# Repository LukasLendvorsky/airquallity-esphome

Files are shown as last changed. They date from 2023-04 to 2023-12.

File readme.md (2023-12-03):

# AirquaLLity-esphome

Air-quality sensor (CO2, particulate matter, ...) in a nice 3D printed package with LED bar visualization. Using ESPHome, compatible with HomeAssitant.

## Images

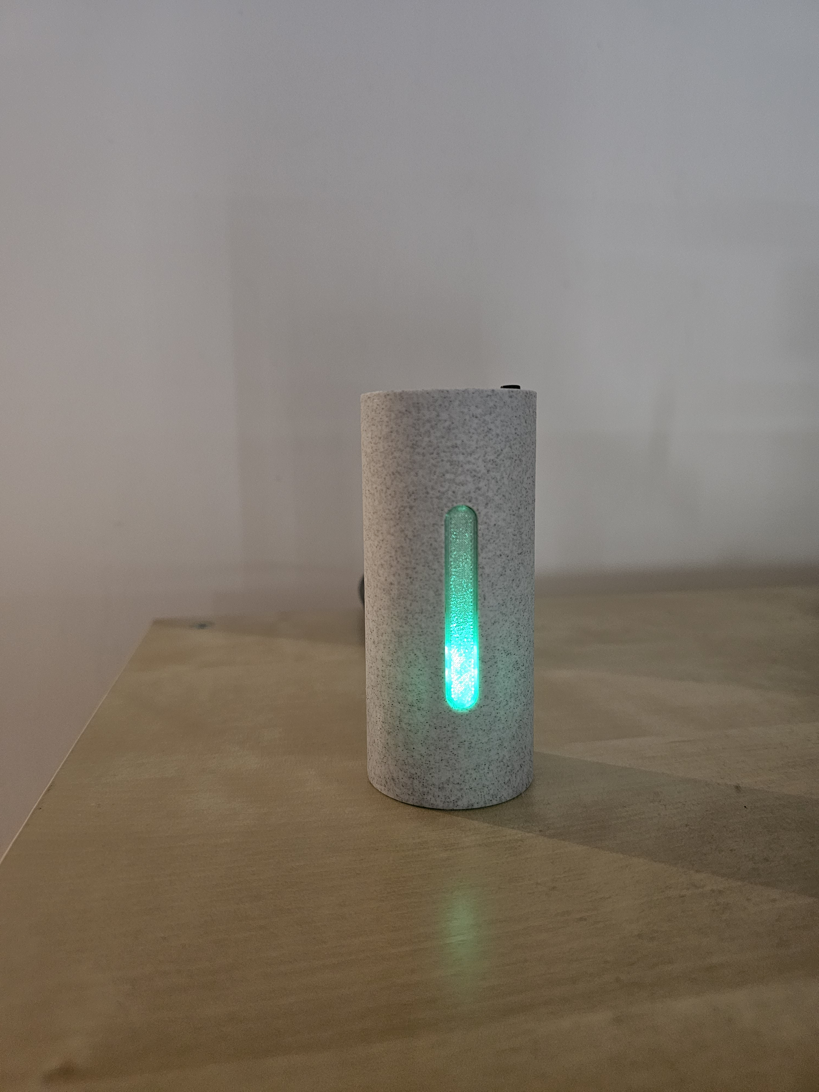
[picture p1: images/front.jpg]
front view

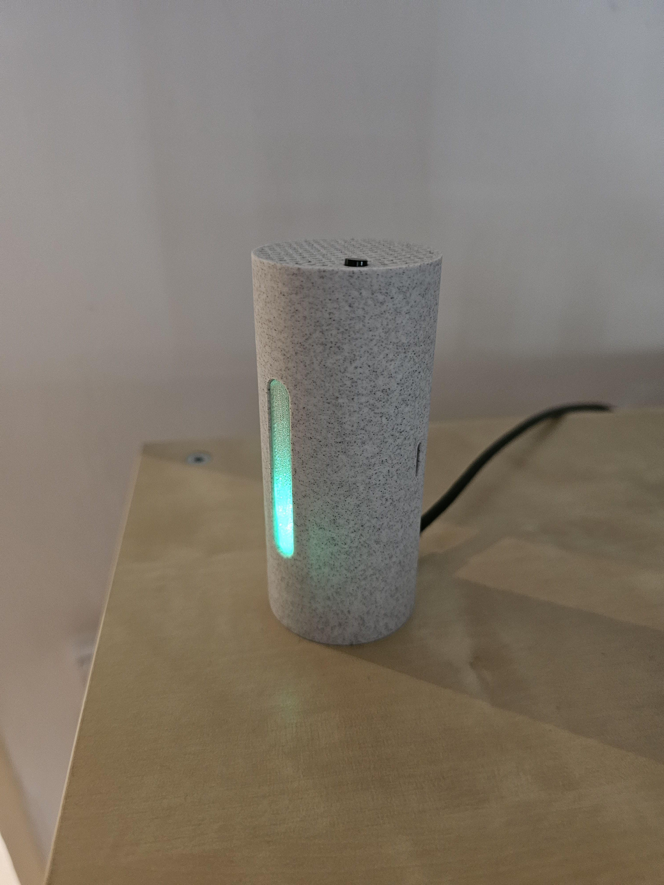
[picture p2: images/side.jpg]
side view


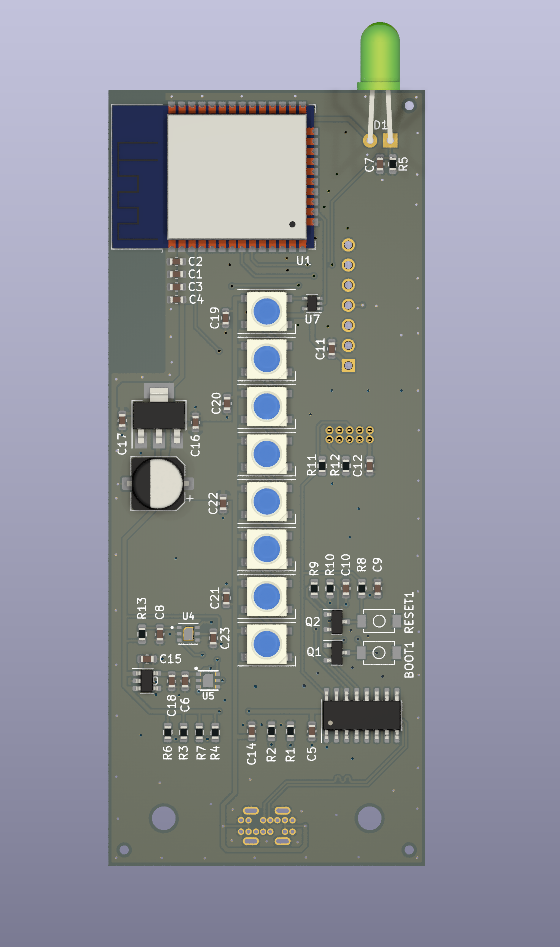
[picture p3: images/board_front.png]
board front view

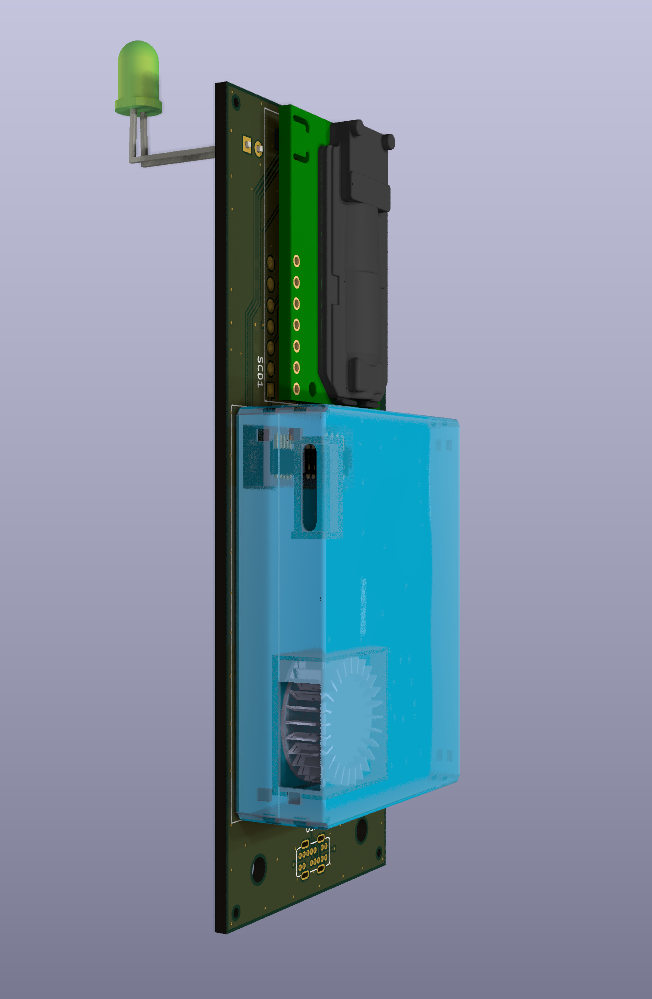
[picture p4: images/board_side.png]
side view


## Features
- Wi-Fi
- RGB LED bar for quick visual air-quality indication
- HomeAssistant compatible

### Sensors:
 - Accurate CO2 using dual NDIR sensor (SCD30) 
 - Particulate matter (<10µm, <2.5µm, <1µm)
 - Temperature
 - Humidity
 - Illumination (amount of light)
 - VOC (Volatile organic compound) sensor
 - NOx sensor

## How to build

Manufactury files available, see schematic/jlcpcb. They can assemble most of the bord, however you'll need to solder at least CO2 sensor & particulate matter sensor yourself.

## Firmware 
 See https://esphome.io/guides/getting_started_command_line.html

- set your Wi-Fi credentials in firmware\secrets.yaml
- go to firmware directory
- Run: ```esphome run llairquality.yaml```

## License

See [LICENSE](LICENSE)

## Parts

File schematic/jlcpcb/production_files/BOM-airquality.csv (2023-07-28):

Comment | Designator | Footprint | LCSC
ALS-PDIC243-3B | D1 | ALS-PDIC243-3B | C141718
100nF | C10,C2,C3,C4,C5,C6,C7 | C_0603_1608Metric | C14663
5K1 | R1,R2 | R_0603_1608Metric | C14677
SCD30 (CO2) | SCD1 | MODULE_SCD30 | C1519271
1uF | C15,C18,C23,C8 | C_0603_1608Metric | C15849
BC817 | Q1,Q2 | SOT-23 | C2137
4.7 | R13 | R_0603_1608Metric | C23164
10K | R10,R11,R12,R3,R4,R5,R6,R7,R8,R9 | R_0603_1608Metric | C25804
WS2812B | D2,D3,D4,D5,D6,D7,D8,D9 | LED_WS2812B_PLCC4_5.0x5.0mm_P3.2mm | C2761795
USB_C_Receptacle | USB1 | Hanbo Electronic MC-802YC-H100 | C3039300
SGP41-D-R4 | U4 | XDCR_SGP41-D-R4 | C3659325
TLV70218_SOT23-5 | U9 | SOT-23-5 | C44435
SGP30 | U5 | SGP30 | C514454
ESP32-WROOM-32D | U1 | ESP32-WROOM-32D | C529577
22uF | C1,C11,C12,C14,C16,C17,C19,C20,C21,C22,C9 | C_0603_1608Metric | C59461
AMS1117-3.3 | U8 | SOT-223-3_TabPin2 | C6186
C_Polarized | C13 | CP_Elec_6.3x5.4 | C72494
SN74LV1T34DCK | U7 | SOT-353_SC-70-5 | C78541
SW_Push | BOOT1,RESET1 | GT-TC029B-H025-L1N | C843669
CH340C | U2 | SOIC-16_3.9x9.9mm_P1.27mm | C84681
PMS7003T | U3 | PMS7003

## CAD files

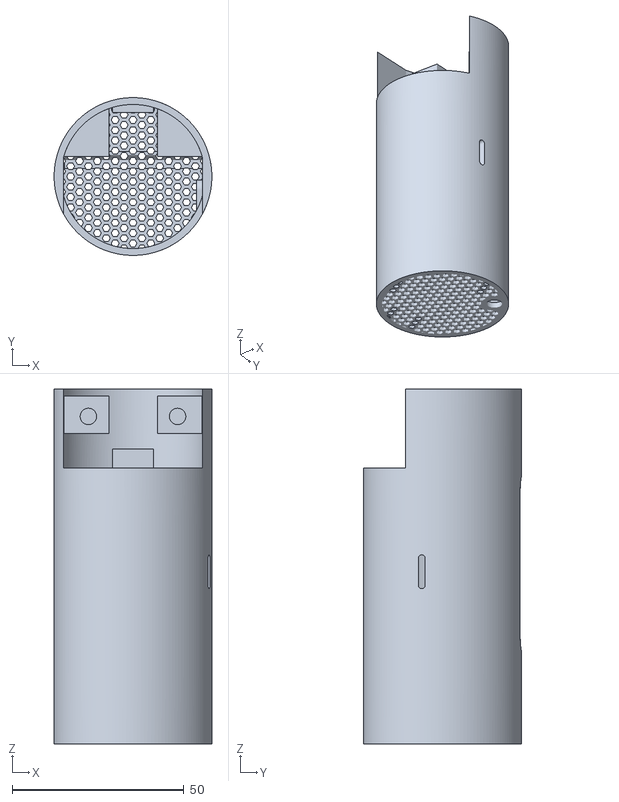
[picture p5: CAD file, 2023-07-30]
case/Case1.stl
46.0 x 46.0 x 103.5

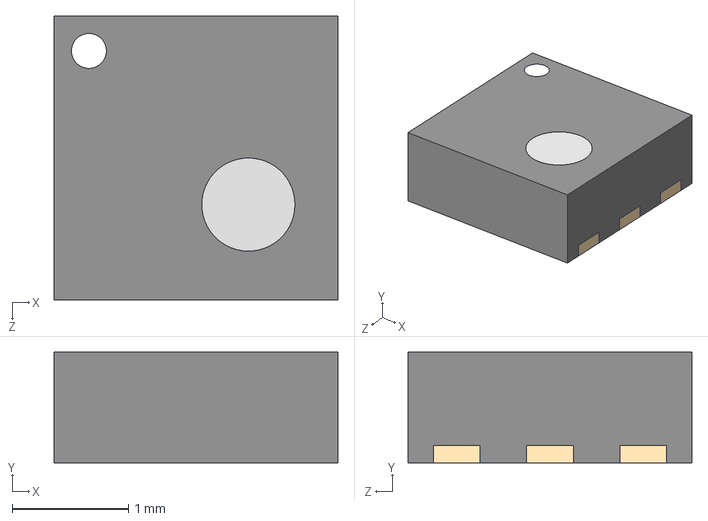
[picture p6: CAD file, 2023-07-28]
schematic/symbols/SGP41-D-R4.step
2.44 x 0.95 x 2.44 mm

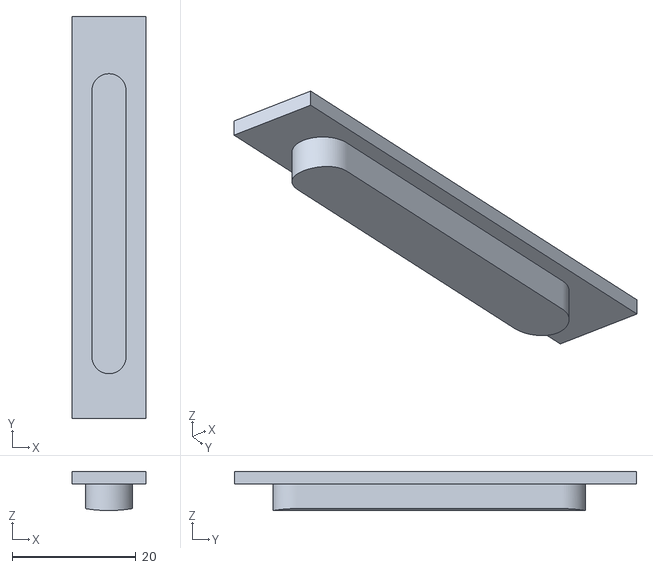
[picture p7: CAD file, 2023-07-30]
case/LighBar.stl
11.9 x 64.9 x 6.32

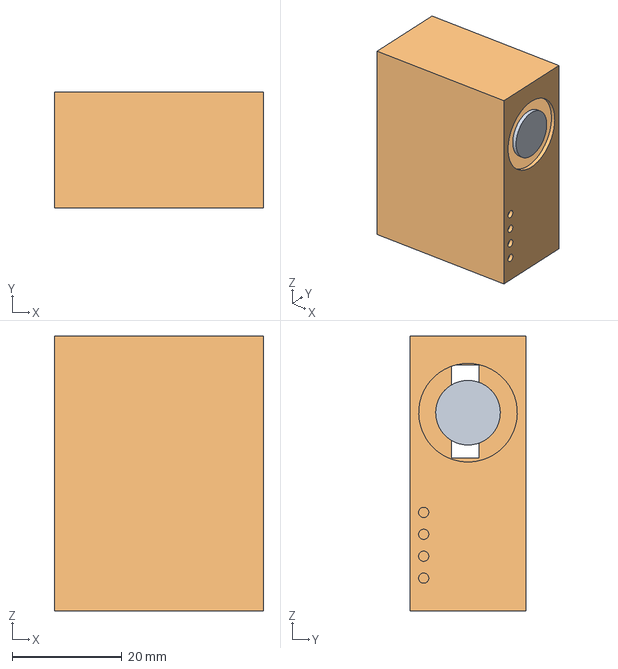
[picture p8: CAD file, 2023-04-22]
schematic/symbols/pms5003.stp
38.2 x 21.2 x 50.2 mm

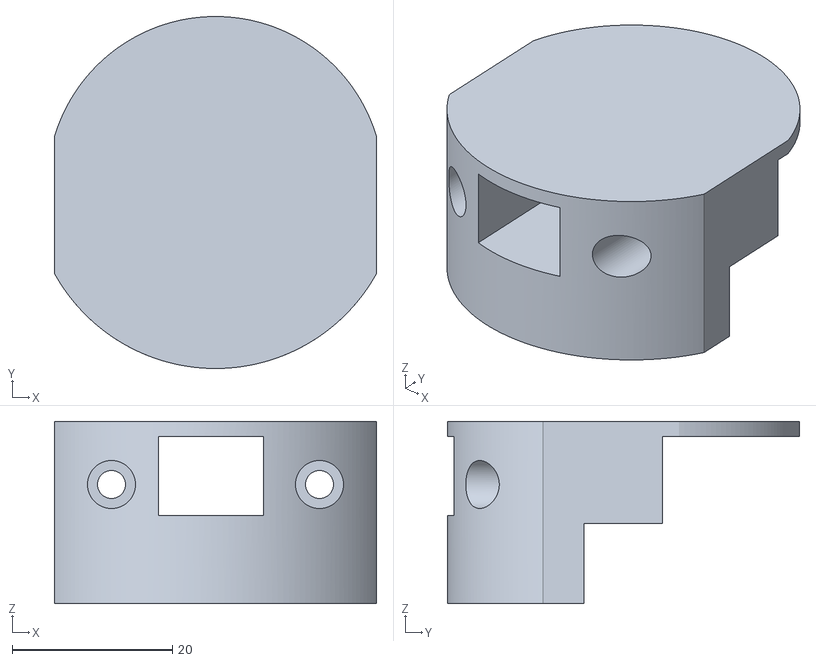
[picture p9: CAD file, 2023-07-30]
case/BottomCap.stl
40.3 x 44.0 x 22.8

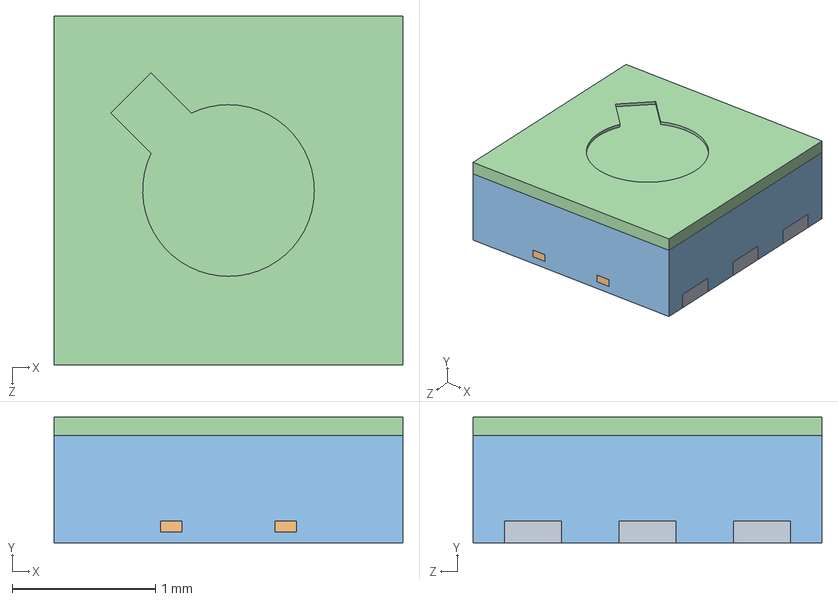
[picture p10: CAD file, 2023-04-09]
schematic/symbols/SGP30-2.5K--3DModel-STEP-1.STEP
2.44 x 0.88 x 2.44 mm

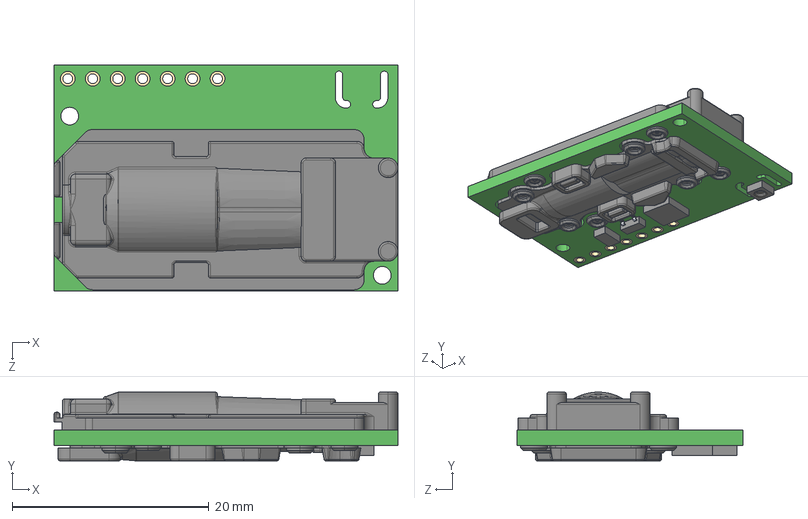
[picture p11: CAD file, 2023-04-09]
schematic/symbols/SCD30.step
35.0 x 7.00 x 23.0 mm

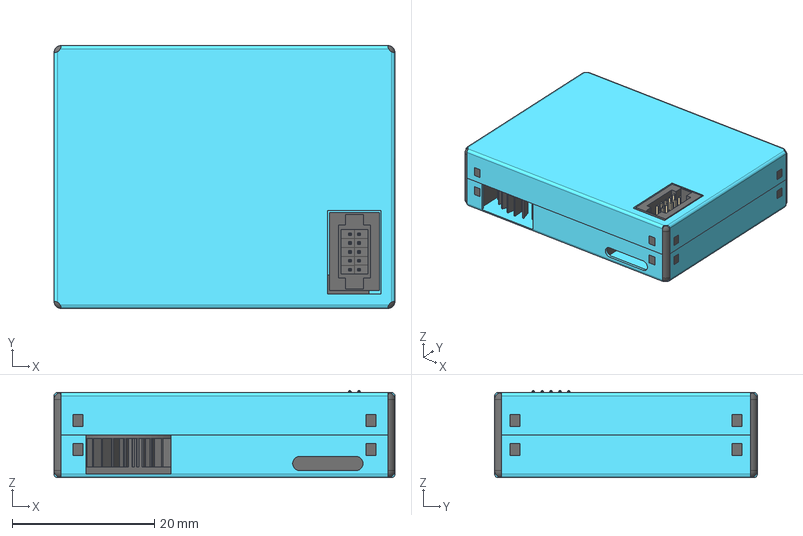
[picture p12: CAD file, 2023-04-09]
schematic/symbols/pms7003.stp
48.0 x 37.0 x 12.3 mm
fan^pms7003
plastic^pms7003
metal_cover_connector
metal_cover_connector_1
1_27mm_pin_right_angle x 10
1_27mm_plastic_for_pin x 10

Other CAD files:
schematic/symbols/pms5003.ipt

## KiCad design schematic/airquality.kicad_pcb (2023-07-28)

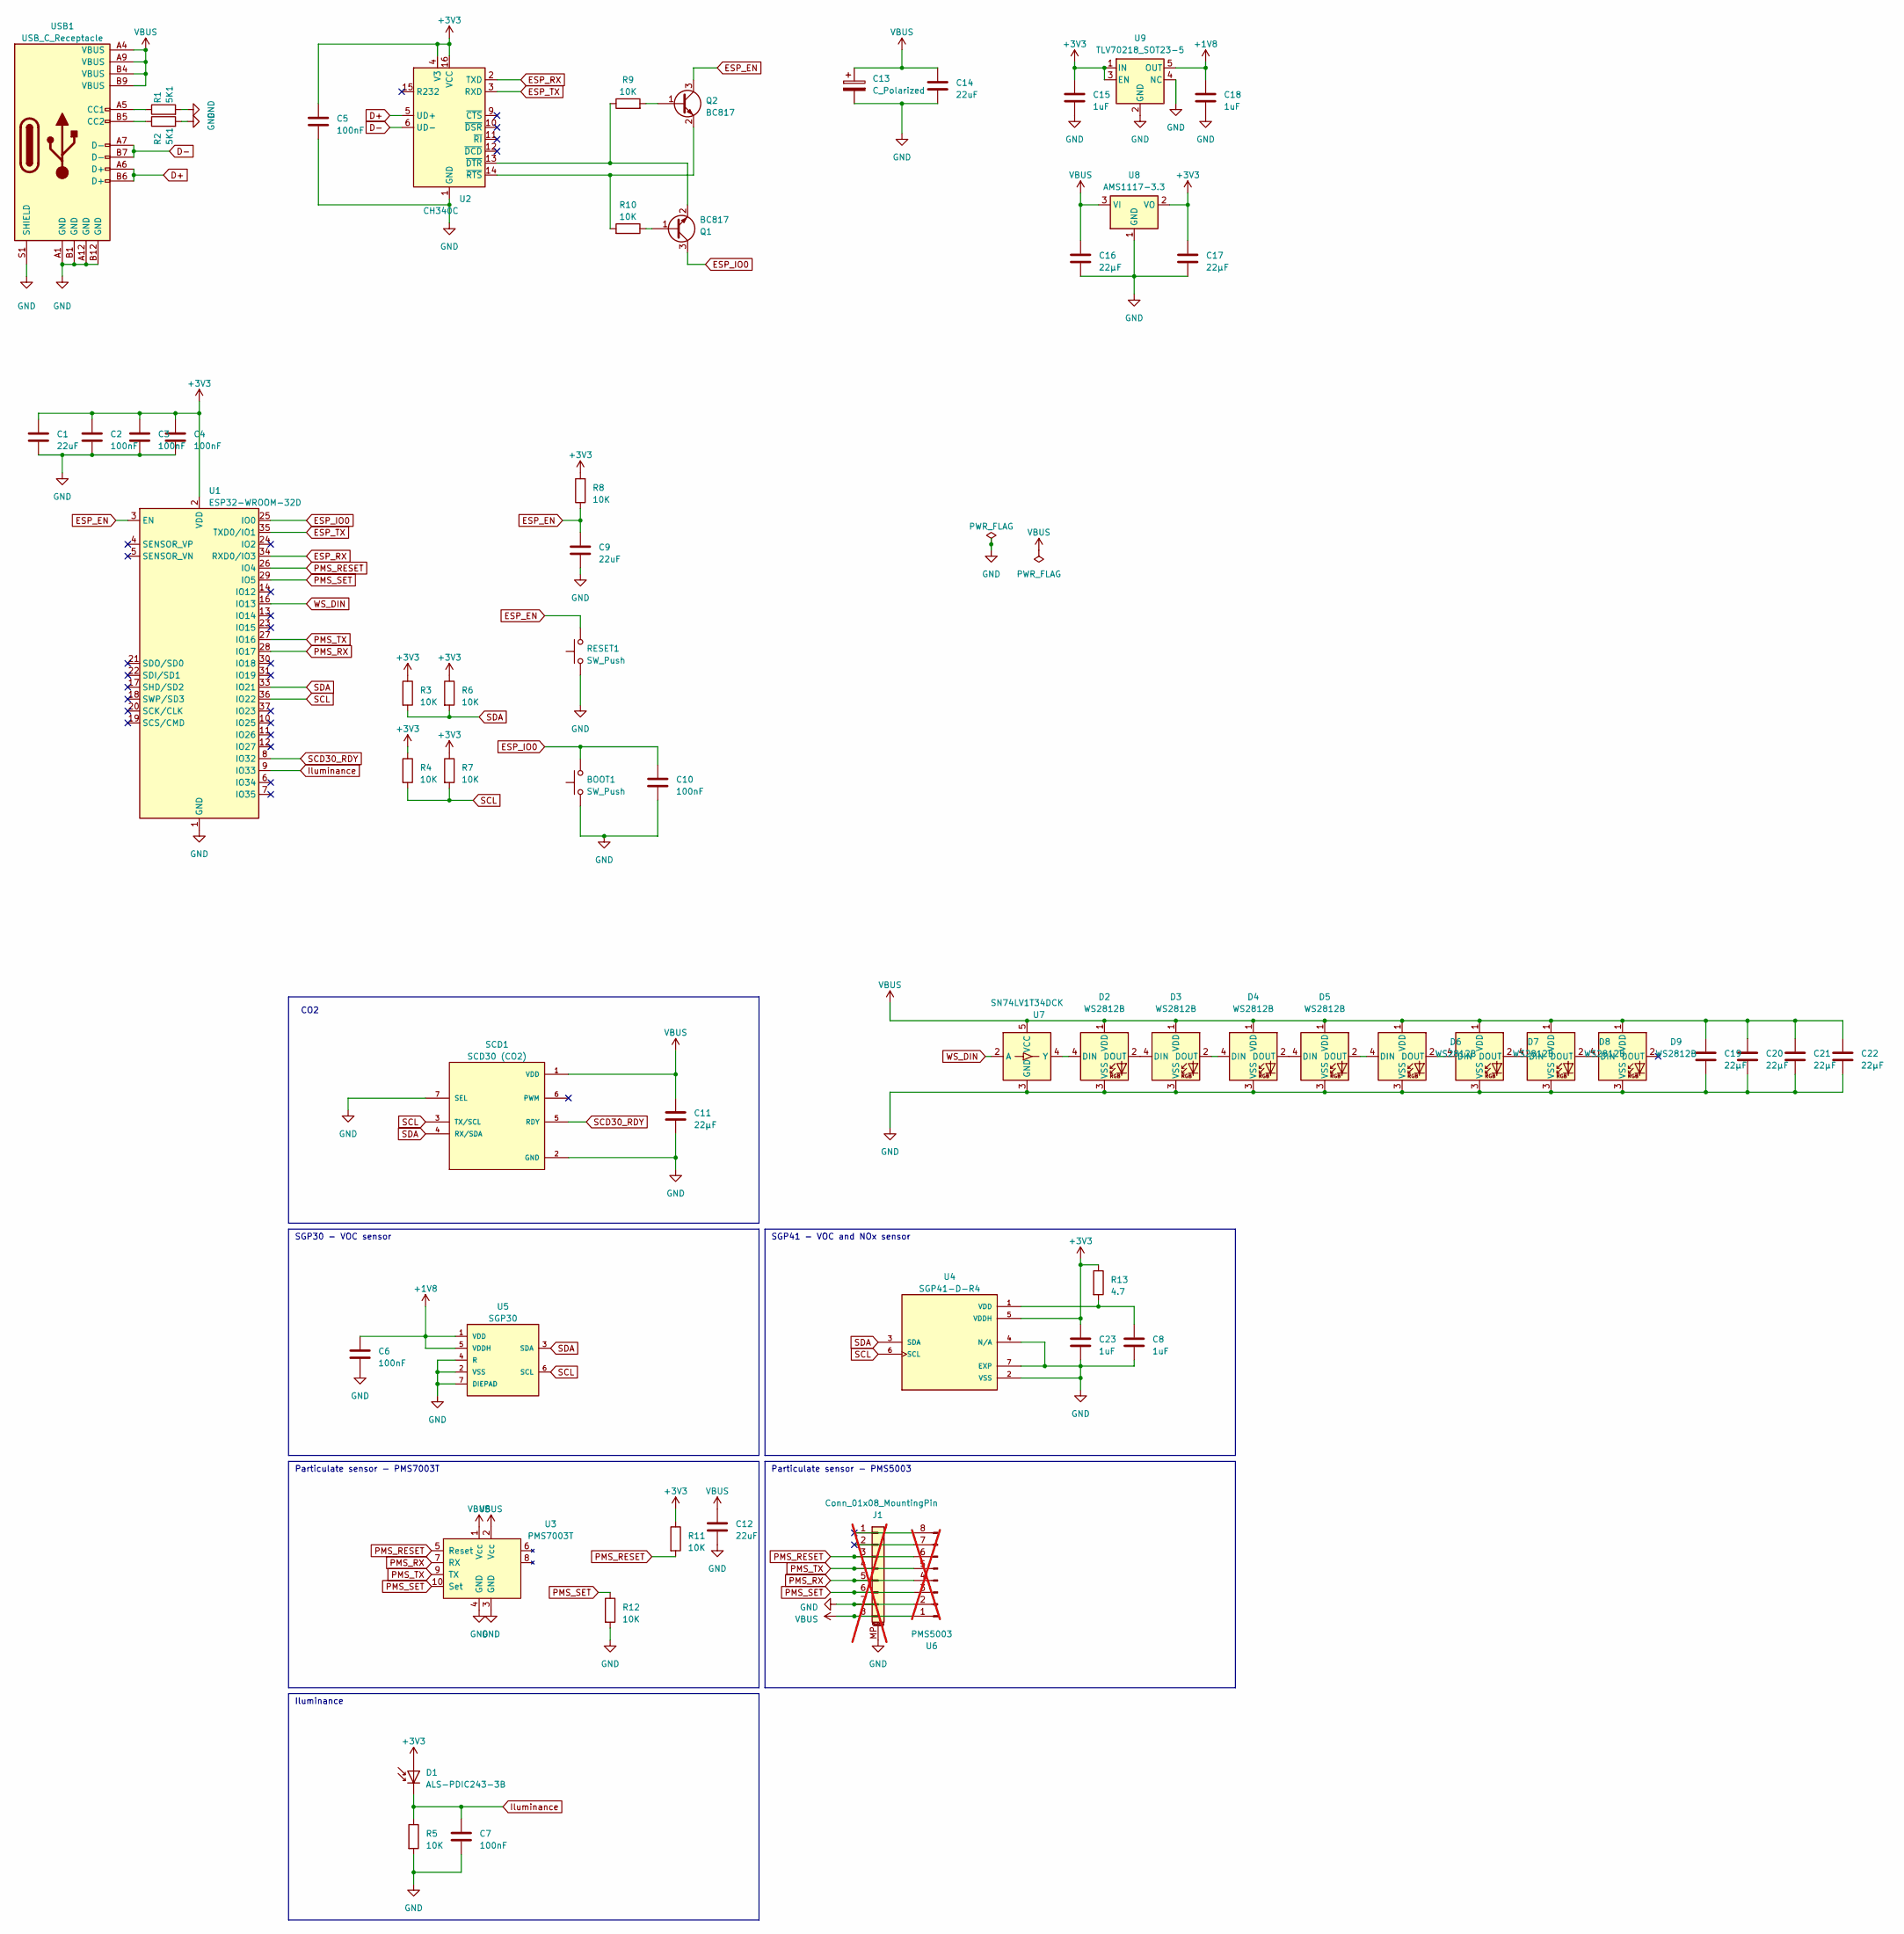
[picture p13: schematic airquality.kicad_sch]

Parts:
BOOT1: SW_Push; GT-TC029B-H025-L1N
C1, C9, C12, C14: 22uF; C_0603_1608Metric
C2, C3, C4, C5, C6, C7, C10: 100nF; C_0603_1608Metric
C8, C15, C18, C23: 1uF; C_0603_1608Metric
C11, C16, C17, C19, C20, C21, C22: 22µF; C_0603_1608Metric
C13: C_Polarized; CP_Elec_6.3x5.4
D1: ALS-PDIC243-3B
D2, D3, D4, D5, D6, D7, D8, D9: WS2812B; LED_WS2812B_PLCC4_5.0x5.0mm_P3.2mm
J1: Conn_01x08_MountingPin; Molex_PicoBlade_53261-0871_1x08-1MP_P1.25mm_Horizontal; not fitted
Q1, Q2: BC817; SOT-23
R1, R2: 5K1; R_0603_1608Metric
R3, R4, R5, R6, R7, R8, R9, R10, R11, R12: 10K; R_0603_1608Metric
R13: 4.7; R_0603_1608Metric
RESET1: SW_Push; GT-TC029B-H025-L1N
SCD1: SCD30 (CO2); MODULE_SCD30; PARTREV D1
U1: ESP32-WROOM-32D
U2: CH340C; SOIC-16_3.9x9.9mm_P1.27mm
U3: PMS7003T; PMS7003
U4: SGP41-D-R4; XDCR_SGP41-D-R4; PARTREV 1.0
U5: SGP30
U6: PMS5003; not fitted
U7: SN74LV1T34DCK; SOT-353_SC-70-5
U8: AMS1117-3.3; SOT-223-3_TabPin2
U9: TLV70218_SOT23-5; SOT-23-5
USB1: USB_C_Receptacle; Hanbo Electronic MC-802YC-H100

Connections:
+1V8: C6.1, C18.1, U5.1 (VDD), U5.5 (VDDH), U9.5 (OUT)
+3V3: C1.1, C2.1, C3.1, C4.1, C5.1, C15.1, C17.1, C23.1, D1.2 (A), R3.1, R4.1, R6.1, R7.1, R8.2, R11.1, R13.1, U1.2 (VDD), U2.4 (V3), U2.16 (VCC), U4.5 (VDDH), U8.2 (VO), U9.1 (IN), U9.3 (EN)
D+: U2.5 (UD+), USB1.A6 (D+), USB1.B6 (D+)
D-: U2.6 (UD-), USB1.A7 (D-), USB1.B7 (D-)
ESP_EN: C9.1, Q2.3 (C), R8.1, RESET1.2, U1.3 (EN)
ESP_IO0: BOOT1.2, C10.1, Q1.3 (C), U1.25 (IO0)
ESP_RX: U1.34 (RXD0/IO3), U2.2 (TXD)
ESP_TX: U1.35 (TXD0/IO1), U2.3 (RXD)
GND: BOOT1.1, C1.2, C2.2, C3.2, C4.2, C5.2, C6.2, C7.2, C8.2, C9.2, C10.2, C11.2, C12.2, C13.2, C14.2, C15.2, C16.2, C17.2, C18.2, C19.2, C20.2, C21.2, C22.2, C23.2, D2.3 (VSS), D3.3 (VSS), D4.3 (VSS), D5.3 (VSS), D6.3 (VSS), D7.3 (VSS), D8.3 (VSS), D9.3 (VSS), J1.7, J1.MP (MountPin), R1.2, R2.2, R5.2, R12.2, RESET1.1, SCD1.2 (GND), SCD1.7 (SEL), U1.1 (GND), U1.15 (GND), U1.38 (GND), U1.39 (GND), U2.1 (GND), U3.3 (GND), U3.4 (GND), U4.2 (VSS), U4.4 (N/A), U4.7 (EXP), U5.2 (VSS), U5.4 (R), U5.7 (DIEPAD), U6.2, U7.3 (GND), U8.1 (GND), U9.2 (GND), U9.4 (NC), USB1.A1 (GND), USB1.A12 (GND), USB1.B1 (GND), USB1.B12 (GND), USB1.S1 (SHIELD)
Iluminance: C7.1, D1.1 (K), R5.1, U1.9 (IO33)
unnamed: D2.4 (DIN), U7.4 (Y)
unnamed: D2.2 (DOUT), D3.4 (DIN)
unnamed: D3.2 (DOUT), D4.4 (DIN)
unnamed: D4.2 (DOUT), D5.4 (DIN)
unnamed: D5.2 (DOUT), D6.4 (DIN)
unnamed: D6.2 (DOUT), D7.4 (DIN)
unnamed: D7.2 (DOUT), D8.4 (DIN)
unnamed: D8.2 (DOUT), D9.4 (DIN)
unnamed: J1.1, U6.8
unnamed: J1.2, U6.7
unnamed: Q1.1 (B), R10.1
unnamed: Q1.2 (E), R9.1, U2.13 (~DTR)
unnamed: Q2.1 (B), R9.2
unnamed: Q2.2 (E), R10.2, U2.14 (~RTS)
unnamed: C8.1, R13.2, U4.1 (VDD)
unnamed: R1.1, USB1.A5 (CC1)
unnamed: R2.1, USB1.B5 (CC2)
PMS_RESET: J1.3, R11.2, U1.26 (IO4), U3.5 (Reset), U6.6
PMS_RX: J1.5, U1.28 (IO17), U3.7 (RX), U6.4
PMS_SET: J1.6, R12.1, U1.29 (IO5), U3.10 (Set), U6.3
PMS_TX: J1.4, U1.27 (IO16), U3.9 (TX), U6.5
SCD30_RDY: SCD1.5 (RDY), U1.8 (IO32)
SCL: R4.2, R7.2, SCD1.3 (TX/SCL), U1.36 (IO22), U4.6 (SCL), U5.6 (SCL)
SDA: R3.2, R6.2, SCD1.4 (RX/SDA), U1.33 (IO21), U4.3 (SDA), U5.3 (SDA)
VBUS: C11.1, C12.1, C13.1, C14.1, C16.1, C19.1, C20.1, C21.1, C22.1, D2.1 (VDD), D3.1 (VDD), D4.1 (VDD), D5.1 (VDD), D6.1 (VDD), D7.1 (VDD), D8.1 (VDD), D9.1 (VDD), J1.8, SCD1.1 (VDD), U3.1 (Vcc), U3.2 (Vcc), U6.1, U7.5 (VCC), U8.3 (VI), USB1.A4 (VBUS), USB1.A9 (VBUS), USB1.B4 (VBUS), USB1.B9 (VBUS)
WS_DIN: U1.16 (IO13), U7.2 (A)

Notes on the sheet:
Iluminance
Particulate sensor - PMS5003
CO2
SGP30 - VOC sensor
SGP41 - VOC and NOx sensor
Particulate sensor - PMS7003T

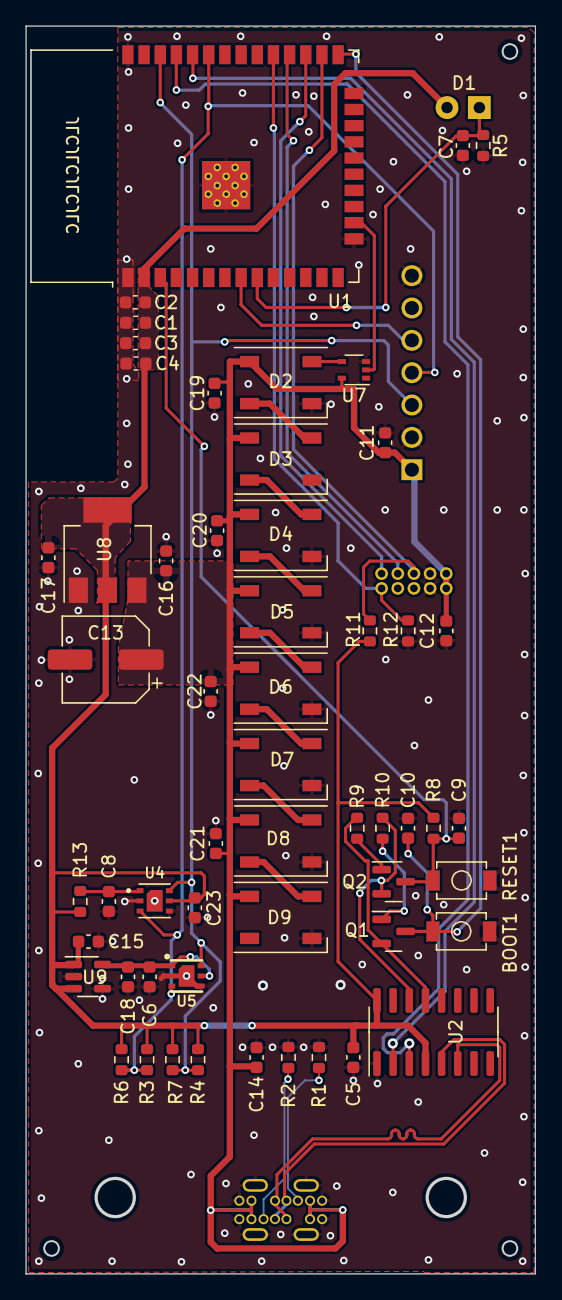
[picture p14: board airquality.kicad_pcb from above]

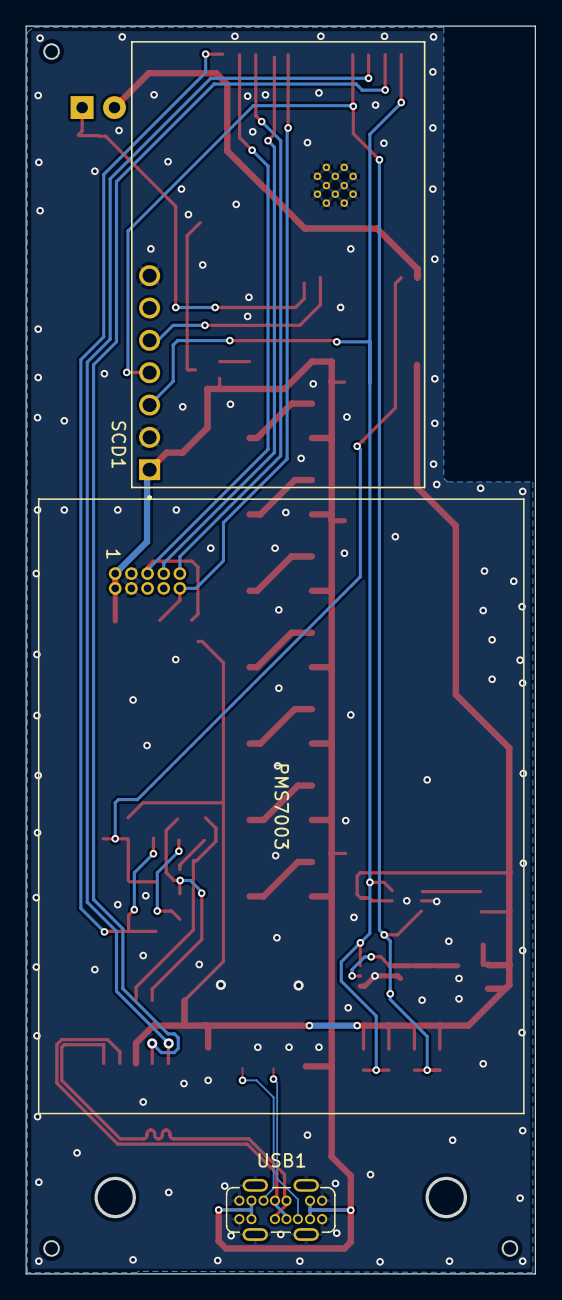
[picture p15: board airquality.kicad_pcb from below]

Board: 2 copper layers, 40.0 x 98.0 mm, 59 parts (3 on the bottom side), 34 nets.

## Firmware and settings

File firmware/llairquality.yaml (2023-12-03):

substitutions:
  devicename: mancave-airquality
  upper_devicename: Mancave Airquality

esphome:
  name: $devicename
  includes:
    "helpers.hpp"
  on_boot: 
      - priority: 500
        then:
          - output.turn_on: PMSReset
          - output.turn_on: PMSSet
      - priority: 300
        then:
            - light.turn_on:
                id: indicator
                effect: Boot
                brightness: 25%
      - priority: -100
        then:
          - light.turn_on:
              id: indicator
              effect: IndicatorEffect
              brightness: 20%


esp32:
  board: nodemcu-32s
  framework:
    type: arduino


# Enable logging
logger:

# Enable Home Assistant API
api:

ota:
  password: ""

wifi:
  ssid: !secret wifi_ssid
  password: !secret wifi_password

  # Enable fallback hotspot (captive portal) in case wifi connection fails
  ap:
    ssid: "$upper_devicename Hotspot"
    password: "zhp7t0DdJt3d"


globals:
   - id: ind_worst # indicator of worst metric of air quality, used for led strip
     type: int
     restore_value: no
     initial_value: '100'
     setup_priority: 1000

captive_portal:

web_server:
  port: 80

# I2C port for sensors
i2c:
  scl: GPIO22
  sda: GPIO21
  frequency: 100kHz

# UART for PMS5003
uart:
  - rx_pin: GPIO16
    tx_pin: GPIO17
    baud_rate: 9600
    id: pms

light:
  - platform: neopixelbus
    type: GRB
    variant: WS2812
    pin: GPIO13
    num_leds: 8
    id: indicator
    name: "$upper_devicename Indicator"
    restore_mode: RESTORE_AND_OFF
    effects:
      - addressable_scan:
          name: Boot
          move_interval: 100ms
          scan_width: 1
      - addressable_lambda:
          name: "IndicatorEffect"
          update_interval: 1s
          lambda: |-
            float val = id(ind_worst);
            Color c = green_to_red((100-val)/100.0);
            it.all() = Color::BLACK;
            uint8_t num = round(val / 100.0 * 8);
            it.range(8-num, 8) = c;


sensor:
  # particulate sensor
  - platform: pmsx003
    type: PMS5003T
    pm_1_0:
      name: "$upper_devicename Particulate Matter <1.0µm Concentration"
      id: pm_1_0
      on_value:
        lambda: 'update_worst();'
    pm_2_5:
      name: "$upper_devicename Particulate Matter <2.5µm Concentration"
      id: pm_2_5
      on_value:
        lambda: 'update_worst();'
    pm_10_0:
      name: "$upper_devicename Particulate Matter <10.0µm Concentration"
      id: pm_10_0
      on_value:
        lambda: 'update_worst();'
    temperature: 
      id: temperature
      name: "$upper_devicename Temperature"
    humidity:
      id: humidity
      name: "$upper_devicename Humidity"

    update_interval: 30s
    uart_id: pms

  #CO2 sensor
  - platform: scd30
    id: co2_sensor
    co2:
      name: "$upper_devicename CO2"
      id: co2
      accuracy_decimals: 1    
      on_value:
        lambda: 'update_worst();'
    temperature:
      name: "$upper_devicename Temperature SCD30"
      id: scd_temperature
      accuracy_decimals: 2
    humidity:
      name: "$upper_devicename Humidity SCD30"
      id: scd_humidity
      accuracy_decimals: 1
    address: 0x61
    update_interval: 5s


  # Air quality indicators (0% = good, 100% = bad)
  - platform: template
    name: "$upper_devicename Indicator CO2"
    id: ind_co2
    lambda: |-
      return to_quality(id(co2).state, 400, 2000);
    update_interval: never
  - platform: template
    name: "$upper_devicename Indicator pm2,5um"
    id: ind_pm2_5
    lambda: |-
      return to_quality(id(pm_2_5).state, 15, 41);
    update_interval: never
  - platform: template
    name: "$upper_devicename Indicator <10.0µm"
    id: ind_pm10
    lambda: |-
      return to_quality(id(pm_10_0).state, 54, 155);
    update_interval: never
  - platform: template
    name: "$upper_devicename Indicator Worst"
    id: ind_worst_sensor
    lambda: |- 
      return id(ind_worst);
    update_interval: never
  
  # VOC + eCO2
  #- platform: sgp30
  #  eco2:
  #    name: "SGP eCO2"
  #    accuracy_decimals: 1
  #  tvoc:
  #    name: "TVOC"
  #    accuracy_decimals: 1
  #  store_baseline: yes
  #  address: 0x58
  #  update_interval: 1s

  # Brightness
  - platform: adc
    pin: GPIO33
    name: "$upper_devicename Brightness"
    update_interval: 1s


output:
  - platform: gpio
    pin: GPIO4
    id: "PMSReset"
  - platform: gpio
    pin: GPIO5
    id: "PMSSet"



button:
  - platform: template
    name: "SCD30 Force manual calibration"
    entity_category: "config"
    on_press:
      then:
        - scd30.force_recalibration_with_reference:
            value: !lambda 'return id(co2_cal).state;'

number:
  - platform: template
    name: "CO2 calibration value"
    optimistic: true
    min_value: 350
    max_value: 4500
    step: 1
    id: co2_cal
    icon: "mdi:molecule-co2"
    entity_category: "config"

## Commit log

2023-04-09 Initial version
    [SCD30.step, SGP30-2.5K--3DModel-STEP-1.STEP, TYPE-C-31-M-12.step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]
2023-04-09 Fix orientation of particulate sensor
    [airquality.kicad_pcb]
2023-04-09 Fix ESP32 model
    [airquality.kicad_pcb]
2023-04-09 PMS700 silk screen on correct side
    [airquality.kicad_pcb]
2023-04-09 MInor silkscreen fixes
    [airquality.kicad_pcb]
2023-04-11 Fix iluminance pin, add caps, add optional double pullups for I2C, cleaup
    [airquality.kicad_pcb, airquality.kicad_sch]
2023-04-18 Lots of fixes
    [TYPE-C-31-M-12.step, airquality.kicad_pcb, airquality.kicad_sch]
2023-04-22 swap PMS7003 with PMS5003
    [airquality.kicad_pcb, airquality.kicad_sch, pms5003.stp]
2023-04-22 Mounting holes
    [airquality.kicad_pcb]
2023-04-22 jlcpcb export
    [BOM-airquality.csv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]
2023-07-28 New board revision
    [BOM-airquality.csv, SGP41-D-R4.step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]
2023-12-03 Add commented SGP30 sensor
2023-12-03 Add board images
